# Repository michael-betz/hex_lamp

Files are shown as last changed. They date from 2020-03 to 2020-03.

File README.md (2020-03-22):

# hex_lamp
Geometric lamp casting wild shadows. [See also this blog post.](https://yetifrisstlama.github.io/hex-lamp/)

hex_lamp shadows

## firmware
Based on 3 perlin noise generators doing a slow random walk, controlling H, S and V of each LED.

  * Install [PlatformIO](https://platformio.org/) 
  * Edit `firmware/platform.ini` to enter the wifi credentials.
  * Connect USB-serial cable to ESP8266
  * Hold the flash button 
  * Build / upload the firmware like this:

```bash
$ platformio run -t upload -t monitor
Processing hexlamp (platform: espressif8266; board: esp01; framework: arduino)
--------------------------------------------------------------------------------------------------------
Verbose mode can be enabled via `-v, --verbose` option
CONFIGURATION: https://docs.platformio.org/page/boards/espressif8266/esp01.html
PLATFORM: Espressif 8266 2.3.2 > Espressif Generic ESP8266 ESP-01 512k
HARDWARE: ESP8266 80MHz, 80KB RAM, 512KB Flash
PACKAGES: 
 - framework-arduinoespressif8266 2.20603.191216 (2.6.3) 
 - tool-esptool 1.413.0 (4.13) 
 - tool-esptoolpy 1.20800.0 (2.8.0) 
 - tool-mkspiffs 1.200.0 (2.0) 
 - toolchain-xtensa 2.40802.191122 (4.8.2)
Converting main.ino
LDF: Library Dependency Finder -> http://bit.ly/configure-pio-ldf
LDF Modes: Finder ~ chain, Compatibility ~ soft
Found 30 compatible libraries
Scanning dependencies...
Dependency Graph
|-- <Adafruit NeoPixel> 1.3.5
|-- <ESP8266WiFi> 1.0
Building in release mode
...
RAM:   [===       ]  33.6% (used 27552 bytes from 81920 bytes)
Flash: [======    ]  63.2% (used 274236 bytes from 434160 bytes)
Creating BIN file ".pio/build/hexlamp/firmware.bin" using ".pio/build/hexlamp/firmware.elf"
Configuring upload protocol...
AVAILABLE: espota, esptool
CURRENT: upload_protocol = esptool
Looking for upload port...
Use manually specified: /dev/ttyUSB0
Uploading .pio/build/hexlamp/firmware.bin
esptool.py v2.8
...
```

## hex_lamp_0
Design files for the first hex_lamp as [featured](https://yetifrisstlama.github.io/hex-lamp/). The design needs to be cut from 1/4" thick material.

  * `.svg` files are the original Inkscape artworks 
  * `.dxf` files are ready to be sent to the laser cutter
  * `joiner.stl` is the 3D printable joiner piece

## `template/hex_lamp.scad`
Parametric model of the lamp in Openscad.
Most important parameters:

  * `a`: side length of the square piece, determining the size of the lamp 
  * `t_sheet`: material thickness

Uncomment the entries at the bottom to export:

  * `2D outlines` of the square and hex piece, with mounting holes
  * `3D .stl file` of the joiner piece

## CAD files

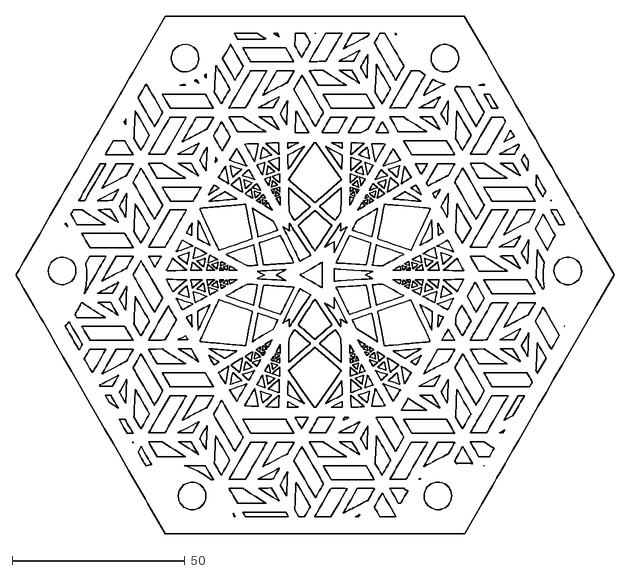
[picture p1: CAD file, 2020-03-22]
hex_lamp_0/dxf/hex_2.dxf
173.1 x 149.9

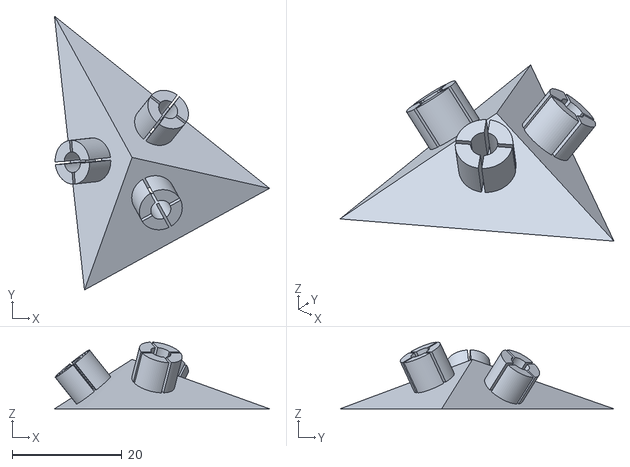
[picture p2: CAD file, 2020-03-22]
hex_lamp_0/joiner.stl
39.1 x 49.8 x 12.1

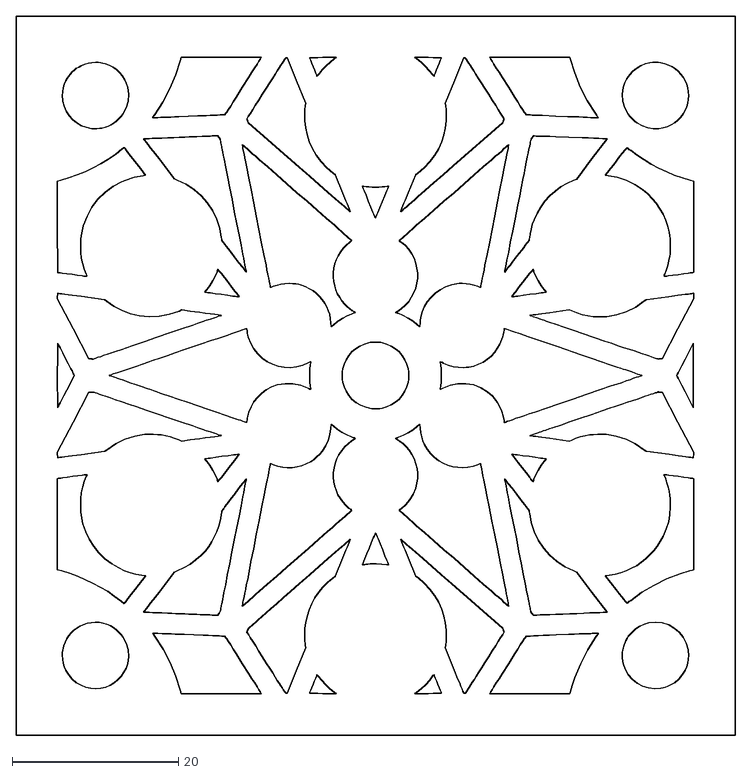
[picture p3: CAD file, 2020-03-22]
hex_lamp_0/dxf/square_1.dxf
86.6 x 86.6

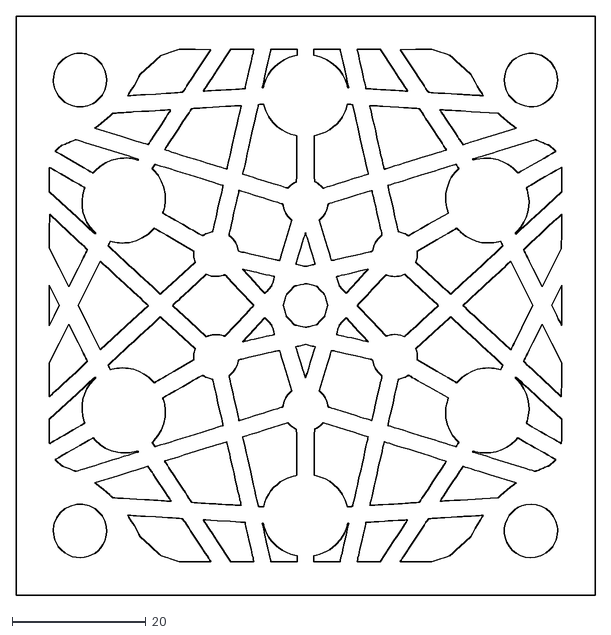
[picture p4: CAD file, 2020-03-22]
hex_lamp_0/dxf/square_0.dxf
86.6 x 86.6

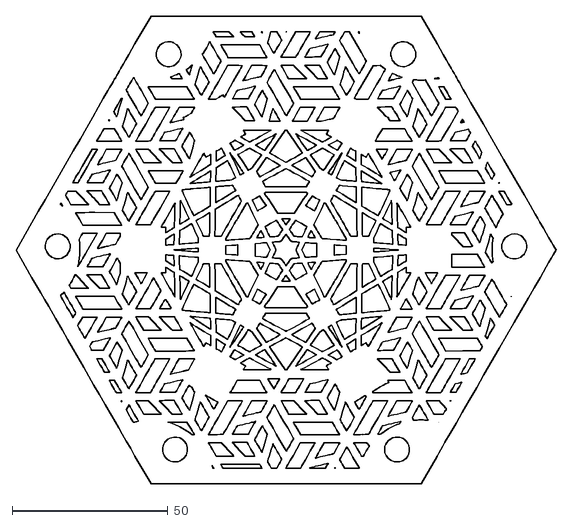
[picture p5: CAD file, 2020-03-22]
hex_lamp_0/dxf/hex_1.dxf
173.1 x 149.9

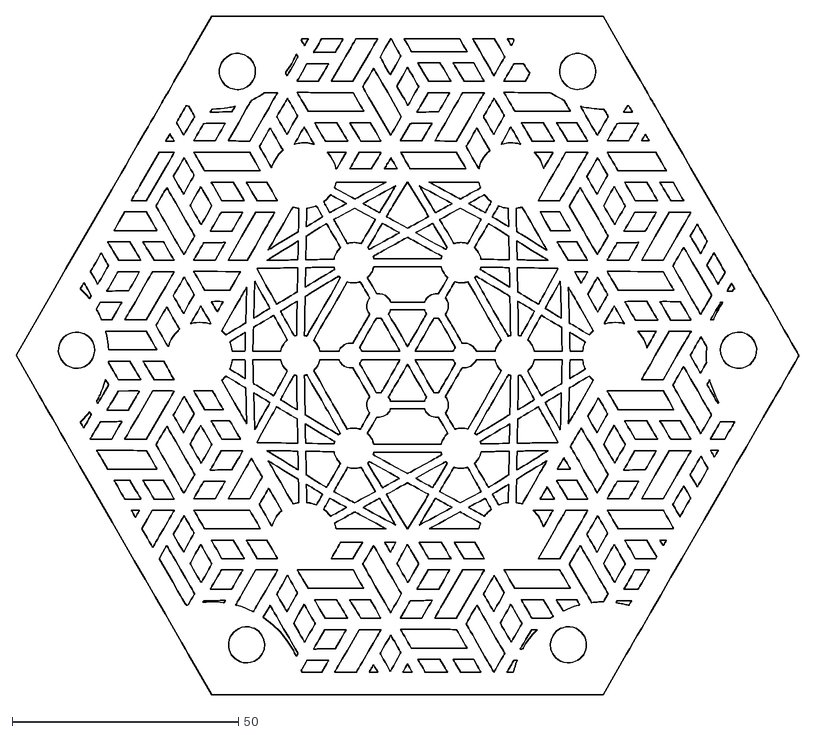
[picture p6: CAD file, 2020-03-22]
hex_lamp_0/dxf/hex_0.dxf
173.1 x 149.9

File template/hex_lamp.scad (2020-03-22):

$fn=75;

a = 86.567;    // Side length on outer (larger) face
hex_rad = sqrt(3) * a / 2; // outer radius of hexagon
t_sheet = 6.2;  // Sheet thickness

r_nipple = 4;
nippel_dist = 9;

// height of lamp when standing on a hexagon face
hexa_height = sqrt(6) * a;
echo("Hexa_height: ", hexa_height);

// height of lamp when standing on a square face
square_height = 2 * sqrt(2) * a;

// Inside angles between the N sided pieces
alpha_4_6 = acos(-1 / sqrt(3));
alpha_6_6 = acos(-1 / 3);

// to move on x and y from outer shell to inner shell. Don't ask how!!
function magic_dist(t_sheet) = 0.517637 * t_sheet;

module move_inside(t_sheet) {
	// Move from the outside wall to the inside wall
	translate([magic_dist(t_sheet), magic_dist(t_sheet), -t_sheet]) children();
}

// 3D shape of the square piece. Need 6 of these for complete shape
module squarepiece(t_sheet, holes=true) {
	module tempHole() {
		translate([nippel_dist / sqrt(2) + magic_dist(t_sheet), -nippel_dist / sqrt(2) - magic_dist(t_sheet), 0])
			translate([-a / 2, a / 2, 0])
				translate([0, 0, -1]) cylinder(h=t_sheet + 2, r=r_nipple, center=false);
	}
	translate([0, 0, -t_sheet]) difference() {
		translate([0, 0, t_sheet / 2]) cube(size=[a, a, t_sheet], center=true);
		// Take the 4 edges off at alpha_4_6
		for (alpha=[0:90:270]) {
			cut_angle = (180 - alpha_4_6) / 2;
			cut_dist = t_sheet * tan(cut_angle);
			rotate([0, 0, alpha])
				translate([0, -a / 2 + cut_dist, 0])
					rotate([cut_angle, 0, 0])
						translate([0, -t_sheet, t_sheet])
							cube(size=[a + t_sheet * 2, t_sheet * 2, t_sheet * 2], center=true);
		}
		// Drill the 4 holes
		if (holes) {
			tempHole();
			mirror([1, 0, 0]) tempHole();
			mirror([0, 1, 0]){
				tempHole();
				mirror([1, 0, 0]) tempHole();
			}
		}
	}
}

// 3D shape of the hexagonal piece. Need 8 of these for complete shape
module hexpiece(t_sheet, holes=true) {
	fn = 6;
	fudge = 1 / cos(180 / fn);

	module tempHole() {
		translate([-a / 2, -hex_rad, -1])
			translate([magic_dist(t_sheet), magic_dist(t_sheet), 0])
				rotate([0, 0, 60]) translate([nippel_dist, 0, 0])
					cylinder(h=t_sheet + 2, r=r_nipple);
	}

	translate([0, 0, -t_sheet]) difference() {
		cylinder(h=t_sheet, r=hex_rad * fudge, $fn=fn);

		// Take the 6 edges off
		// alternating at the 4_6 and 6_6 angle
		for (alpha=[0:60:300]) {
			tmp = (alpha % 120) == 0 ? alpha_4_6 : alpha_6_6;
			cut_angle = (180 - tmp) / 2;
			cut_dist = t_sheet * tan(cut_angle);
			rotate([0, 0, alpha])
				translate([0, -hex_rad + cut_dist, 0])
					rotate([cut_angle, 0, 0])
						translate([0, -t_sheet, t_sheet])
							cube(size=[a + t_sheet * 2, t_sheet * 2, t_sheet * 2], center=true);
		}

		// Drill the 6 holes, with thickness dependent offset
		if (holes) {
			for (alpha=[0:120:240]) {
				rotate([0, 0, alpha]) tempHole();
				rotate([0, 0, alpha]) mirror([1, 0, 0]) tempHole();
			}
		}
	}
}

//  put 3 side pieces together
module corner_piece(t_sheet=30, holes=true) {
	union() {
		translate([a / 2 - 0.001, hex_rad - 0.001, 0])
			hexpiece(t_sheet, holes);

		rotate([(180 - alpha_4_6), 0, 0])
			translate([a / 2, -a / 2, 0])
				color("green") squarepiece(t_sheet, holes);

		rotate([180 + alpha_6_6, 0, 120])
			translate([a / 2, hex_rad, 0])
				rotate([0, 0, 60])
					color("blue") hexpiece(t_sheet, holes);
	}
}

// one nipple, centered on origin
module nipple_piece(n_r, n_h)
{
	difference() {
		translate([0, 0, n_h / 2]) cylinder(h=n_h, r=n_r, center=true);
		// Cut outs
		cube(size=[11, 0.5, 150], center=true);
		cube(size=[0.5, 11, 150], center=true);
	}
}

// operation to create the 3 nipples with same angle as the 3 corner faces
// nippel_dist is distance from top corner along the face
module position_nipples(nippel_dist)
{
	union() {
		rotate([0, 0, 60])
			translate([nippel_dist, 0, 0])
				children(0);
		rotate([(180 - alpha_4_6), 0, 0])
			rotate([0, 0, -45])
				translate([nippel_dist, 0, 0])
					children(0);
		rotate([180 + alpha_6_6, 0, 120])
			rotate([0, 0, 60])
				translate([nippel_dist, 0, 0])
						children(0);
	}
}

// 3 thick side pieces + 3 nipples
module corner_piece_with_nipples() {
	difference() {
		union() {
			corner_piece(30, false);
			position_nipples(nippel_dist) nipple_piece(r_nipple, t_sheet);
		}
		// Central screw hole through nippel
		position_nipples(nippel_dist)
			cylinder(h=3 * t_sheet, r=3.75 / 2, center=true);
	}
}

// Create the joiner piece by intersecting the above with a cube
module joiner() {
	intersection() {
		// angles fine tuned to get similar area on faces
		corner_piece_with_nipples();
		// translate([0, 0, 70]) sphere(r=80);
		rotate([32, -23, 0]) translate([0, 0, 41]) cube([200, 200, 100], true);
	}
}

// -----------------------------
//  Cross-check the joiners fit
// -----------------------------
// t_sheet = 35;
module tempjoin() {translate([-a / 2, -hex_rad, 0]) move_inside(t_sheet) joiner();}
translate([-a / 2, -hex_rad, 0]) corner_piece(t_sheet);
	for (alpha=[0:120:240]) {
		rotate([0, 0, alpha]) union() {
			tempjoin();
			mirror([1, 0, 0]) tempjoin();
		}
	}

// corner_piece(30, true);

// hexpiece(t_sheet, true);


//-----------------
// Export files
//-----------------
// [joiner.stl]
// translate([0, 0, 9]) rotate([-32, 0, 0]) rotate([0, 23, 0]) joiner();

// [hex.svg]
// projection(cut=true)
// 	translate([0, 0, 0.000001])
// 		hexpiece(t_sheet);

// [square.svg]
// projection(cut=true)
// 	translate([0, 0, 0.000001])
// 		squarepiece(t_sheet);

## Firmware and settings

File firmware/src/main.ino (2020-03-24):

// --------------------------------------
//  Hex lamp WS2812 engine
// --------------------------------------
// based on perlin noise controlling H, S, V
//
// Build / Upload / Monitor it with
// $ platformio run -t upload -t monitor
//
// Rudimentary MQTT interface:
// mosquitto_pub -t "hex_lamp/intensity" -m 0.3
// printf '\x51\x11\x22' | mosquitto_pub -t "hex_lamp/raw" -l

#include <Adafruit_NeoPixel.h>
#include <ESP8266WiFi.h>
#include <WiFiUdp.h>
#include <PubSubClient.h>
#include "perlin.h"

// WS2812 black LED strips
Adafruit_NeoPixel strip(N_LEDS, PIN_DATA, NEO_GRB + NEO_KHZ800);

// MQTT stuff
WiFiClient wifi_client;
PubSubClient client(wifi_client);

// how likely an LED is lit [0.0 .. 1.0]
float g_intensity = 0.5;

// timeout counter: how long to display hex_lamp/raw pixels
unsigned raw_mode = 0;

// Perlin noise seeds
int seed1, seed2, seed3;

// On received MQTT message
void mqtt_cb(char* topic, byte* payload, unsigned int length) {
	Serial.printf("MQTT [%s] ", topic);
	for (unsigned i = 0; i < length; i++) {
		Serial.print((char)payload[i]);
	}
	Serial.println();

	if (strcmp(topic, MQTT_PREFIX "/raw") == 0) {
		// Write raw binary payload to LED strip
		unsigned n = length / 3;

		if (n <= 0)
			return;

		byte *p = payload;

		if (n == 1 || n > N_LEDS)
			n = N_LEDS;

		for (unsigned i=0; i<n; i++) {
			strip.setPixelColor(i, p[0], p[1], p[2]);
			if (length > 3)
				p += 3;
		}

		raw_mode = 1500;  // Raw mode timeout = 1 min
		strip.show();
		return;

	} else if (strcmp(topic, MQTT_PREFIX "/intensity") == 0) {
		// Convert payload to float, set g_intensity
		payload[length] = 0;  // nasty!

		float val = atof((char*)payload);

		if (val >= 0.0 && val <= 1.0) {
			g_intensity = val;
			Serial.printf("g_intensity = %f\n", val);
		}
	}
}

void setup() {
	Serial.begin(115200);

	strip.begin();
	strip.clear();
	strip.setPixelColor(0, 0xFF, 0, 0);
	strip.show();

	client.setServer(MQTT_BROKER, 1883);
	client.setCallback(mqtt_cb);

	WiFi.begin(WIFI_NAME, WIFI_PW);
	Serial.printf("\nThis is hexlamp, connecting to %s \n", WIFI_NAME);

	for (int i=0; i<=500; i++) {
		if (WiFi.status() == WL_CONNECTED) {
			strip.setPixelColor(0, 0, 0xFF, 0);
			strip.show();
			Serial.print("\nConnected! IP: ");
			Serial.println(WiFi.localIP());
			break;
		}
		delay(100);
		Serial.print(".");
	}

	srand(RANDOM_REG32);
	seed1 = rand();
	seed2 = rand();
	seed3 = rand();
}

void mqtt_reconnect() {
	if (WiFi.status() != WL_CONNECTED)
		return;
	Serial.printf("Connecting to MQTT broker %s ... ", MQTT_BROKER);
	if (client.connect(MQTT_BROKER)) {
		Serial.printf("connected!\n");
		Serial.printf("Subscribing to %s\n", MQTT_PREFIX "/#");
		client.subscribe(MQTT_PREFIX "/#");
		return;
	}
	Serial.printf("failed :(\n");
}

// clip b such that: a <= b <= c
static float limit(float a, float b, float c) {
	return ((a > b) ? a : (b > c) ? c : b);
}

void loop() {
	static int tick=0;
	float n1, n2, n3, n3_raw;

	if (!client.connected() && ((tick % 500) == 0)) {
		mqtt_reconnect();
	}
	client.loop();

	if (raw_mode > 0) {
		raw_mode--;
	} else {
		for (int i=0; i<N_LEDS; i++) {
			// Range approximately -1 .. +1
			n1 = pnoise2d(3.1 * i, 0.002 * tick, 0.7, 3, seed1);
			n2 = pnoise2d(7.4 * i, 0.002 * tick, 0.7, 3, seed2);
			n3_raw = pnoise2d(8.9 * i, 0.004 * tick, 0.7, 3, seed3);

			// Color: Shift range to ~ 0 .. +1
			n1 = n1 / 2.0 + 0.5;

			// Saturation: The more positive offset, the more colorful
			n2 = n2 + 0.8;
			n2 = limit(0.0, n2, 1.0);

			// Brightness: negative offset = less likely to light up a LED
			n3_raw = (n3_raw + (g_intensity - 0.75) * 2.0) * 3.0;
			n3 = limit(0.0, n3_raw, 1.0);

			strip.setPixelColor(i, strip.gamma32(strip.ColorHSV(
				n1 * 0xFFFF,
				n2 * 0xFF,
				n3 * 0xFF
			)));
		}
		strip.show();
		Serial.printf(
			"%6d: %6.3f, %6.3f, %6.3f (%6.3f)\n",
			tick, n1, n2, n3, n3_raw
		);
	}

	tick++;
	delay(40);
}

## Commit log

2020-03-22 Add artwork and openscad files
    [hex_0.dxf, hex_1.dxf, hex_2.dxf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]
2020-03-24 firmware: add rudimentary MQTT client
    ... gotta justify the on-board WIFI somehow.
